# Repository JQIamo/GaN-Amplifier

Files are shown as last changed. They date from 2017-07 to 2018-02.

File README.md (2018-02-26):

# GaN-Amplifier
High-power, wideband RF amplifier designed by D. Barker and A. Restelli.
This design is released under the CERN Open Hardware License v1.2.

Primary documentation for the GaN amplifier can be found in the [Wiki](https://github.com/JQIamo/aom-driver/wiki/AOM-Driver-Wiki) for the [GaN-Amp-Compatible](https://github.com/JQIamo/aom-driver/tree/GaN-Amp-Compatible) branch of the AOM driver.

The eagle files in this repository will be much easier to use with [eagle-config](https://github.com/JQIamo/eagle-config) installed and configured.

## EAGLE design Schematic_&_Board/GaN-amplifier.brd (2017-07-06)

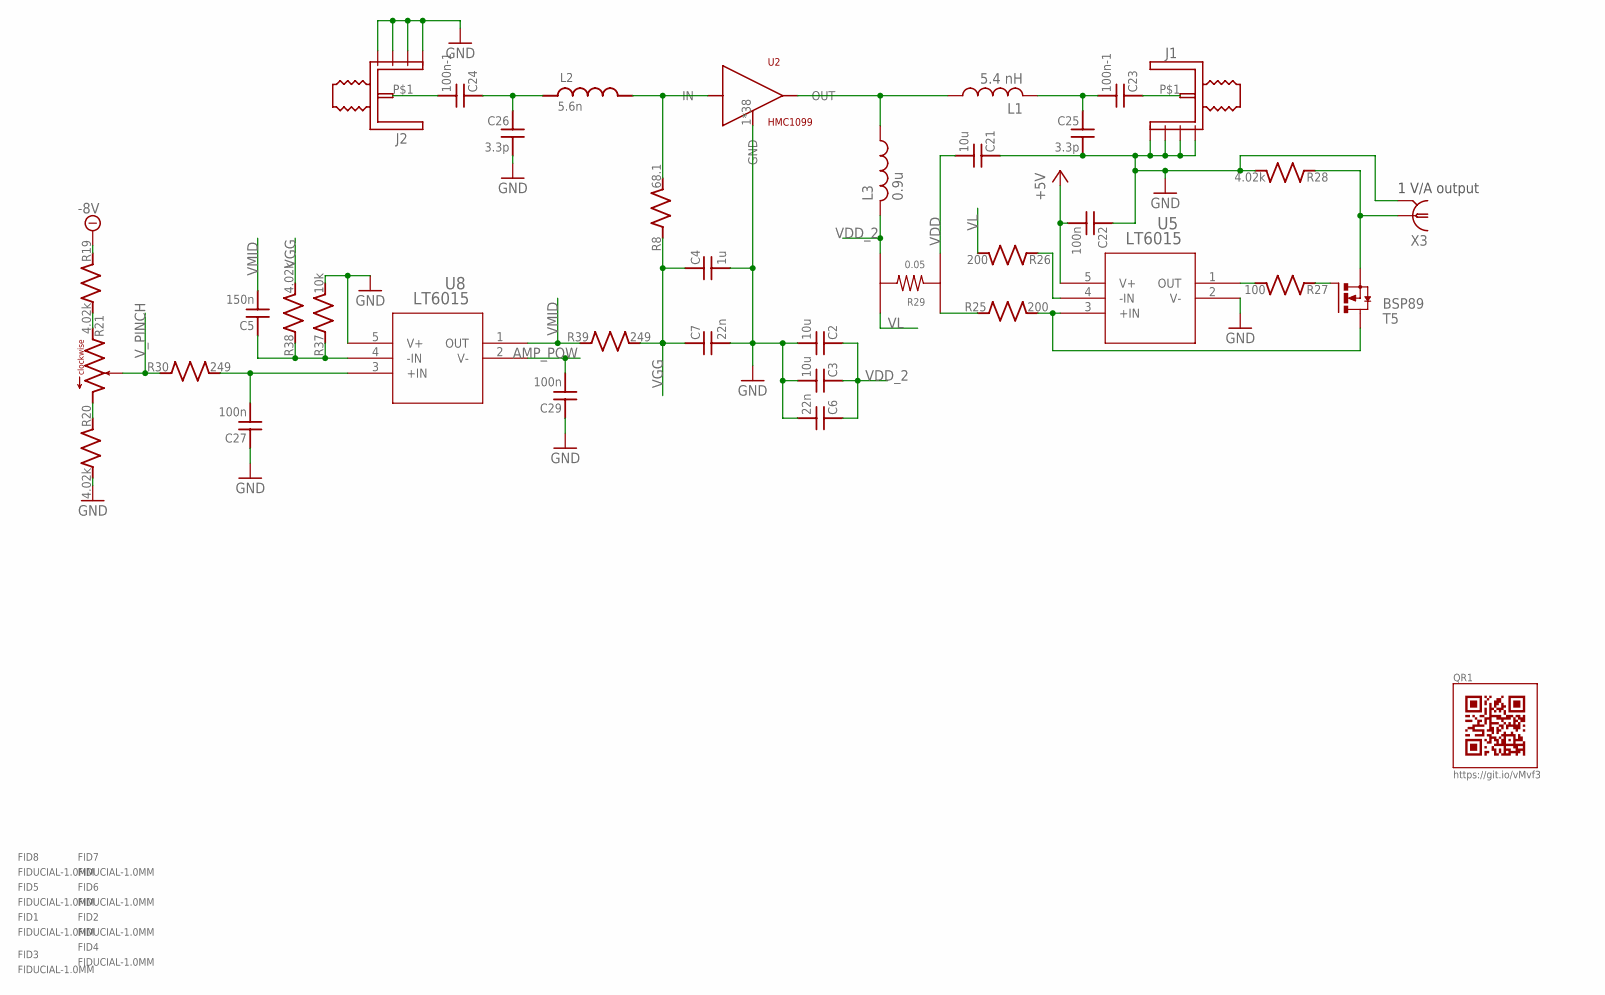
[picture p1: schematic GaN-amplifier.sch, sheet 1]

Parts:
C2, C3, C21: 10u; C_MLCC_1210; PARTNO CL32B106KBJNNNE
C4: 1u; C_MLCC_0603; PARTNO CL10B105KA8NNNC
C5: 150n; C_MLCC_0603; PARTNO CL10B154KO8NNNC
C6, C7: 22n; C_MLCC_0603; PARTNO CL10B223KB8NNNC
C22, C27, C29: 100n; C_MLCC_0603; PARTNO CL10B104KB8SFNC
C23, C24: 100n-1; C_MLCC_0402; PARTNO 0402BB104KW500
C25, C26: 3.3p; C_MLCC_0603; PARTNO 600S3R3CT250XT
FID1, FID2, FID3, FID4, FID5, FID6, FID7, FID8: FIDUCIAL-1.0MM; FID_1.0MM
J1, J2: JOHNSON_SMA_EDGE_LAUNCH_142-0701-851; PARTNO 142-0701-851
L1: 5.4 nH; 0906; PARTNO 0906-5JLB
L2: 5.6n; R_0402; PARTNO 0402CS-5N6XJLU
L3: 0.9u; 1008; PARTNO 1008AF-901XKLC
QR1: QR-HTTPS://GIT.IO/VMVF3-LIGHT-SILK
R8: 68.1; R_0603; PARTNO ERJ-3EKF68R1V
R19, R20, R28, R38: 4.02k; R_0603; PARTNO TNPW06034K02BEEA
R21: R_TRIM; RJ24; PARTNO Y006910K0000J9L
R25, R26: 200; R_0603; PARTNO TNPW0603200RBEEA
R27: 100; R_0603; PARTNO ERJ-3EKF1000V
R29: 0.05; 1206_KELVIN; PARTNO LVK12R050DER
R30, R39: 249; R_0603; PARTNO TNPW0603249RBEEA
R37: 10k; R_0603; PARTNO TNPW060310K0BEEA
T5: BSP89; PG-SOT-223; PARTNO BSP89H6327XTSA1
U2: HMC1099; HCP-32-2; PARTNO HMC1099LP5DE
U5, U8: LT6015; TSOT-23_S5; PARTNO LT6015HS5#TRMPBF
X3: BNC-V; PARTNO 5227222-3

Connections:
+5V: C22.P$2 (2), U5.5 (V+); also elsewhere on the board
-8V: R19.P$1 (1); also elsewhere on the board
AMP_POW: C29.P$2 (2), U8.2 (V-); also elsewhere on the board
GND: C2.P$2 (2), C3.P$2 (2), C4.P$2 (2), C6.P$2 (2), C7.P$2 (2), C21.P$1 (1), C22.P$1 (1), C25.P$2 (2), C26.P$2 (2), C27.P$1 (1), C29.P$1 (1), J1.P$2 (GND1), J1.P$3 (GND), J1.P$4 (GND2), J1.P$5 (GND3), J2.P$2 (GND1), J2.P$3 (GND), J2.P$4 (GND2), J2.P$5 (GND3), R20.P$2 (2), R28.P$2 (2), R37.P$2 (2), U2.1 (GND), U2.2 (GND), U2.3 (GND), U2.6 (GND), U2.7 (GND), U2.8 (GND), U2.9 (GND), U2.10 (GND), U2.11 (GND), U2.12 (GND), U2.13 (GND), U2.14 (GND), U2.15 (GND), U2.16 (GND), U2.17 (GND), U2.18 (GND), U2.19 (GND), U2.22 (GND), U2.23 (GND), U2.24 (GND), U2.25 (GND), U2.26 (GND), U2.27 (GND), U2.28 (GND), U2.29 (GND), U2.30 (GND), U2.31 (GND), U2.32 (GND), U2.33 (GND), U2.34 (GND), U2.35 (GND), U2.36 (GND), U2.37 (GND), U2.38 (GND), U2.39 (GND), U2.40 (GND), U2.41 (GND), U2.42 (GND), U5.2 (V-), U8.5 (V+), X3.2; also elsewhere on the board
unnamed: R19.P$2 (2), R21.1
unnamed: R20.P$1 (1), R21.3
unnamed: R25.P$2 (2), T5.2 (D), T5.4 (D), U5.3 (+IN)
unnamed: R27.P$2 (2), U5.1 (OUT)
unnamed: R27.P$1 (1), T5.1 (G)
unnamed: R25.P$1 (1), R29.P$1
unnamed: R28.P$1 (1), T5.3 (S), X3.1
unnamed: R26.P$1 (1), U5.4 (-IN)
unnamed: C23.P$1 (1), J1.P$1
unnamed: C24.P$2 (2), J2.P$1
unnamed: C5.P$1 (1), R37.P$1 (1), R38.P$1 (1), U8.4 (-IN)
unnamed: C23.P$2 (2), C25.P$1 (1), L1.P$2 (2)
unnamed: L1.P$1 (1), L3.P$1 (1), U2.20 (OUT), U2.21 (OUT)
unnamed: C24.P$1 (1), C26.P$1 (1), L2.P$1 (1)
unnamed: C27.P$2 (2), R30.P$2 (2), U8.3 (+IN)
VDD: C21.P$2 (2), R29.P$3; also elsewhere on the board
VDD_2: C2.P$1 (1), C3.P$1 (1), C6.P$1 (1), L3.P$2 (2), R29.P$4
VGG: C4.P$1 (1), C7.P$1 (1), R8.P$1 (1), R38.P$2 (2), R39.P$2 (2)
VL: R26.P$2 (2), R29.P$2
VMID: C5.P$2 (2), R39.P$1 (1), U8.1 (OUT)
V_GATE: L2.P$2 (2), R8.P$2 (2), U2.4 (IN), U2.5 (IN)
V_PINCH: R21.2, R30.P$1 (1); also elsewhere on the board

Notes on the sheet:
1 V/A output

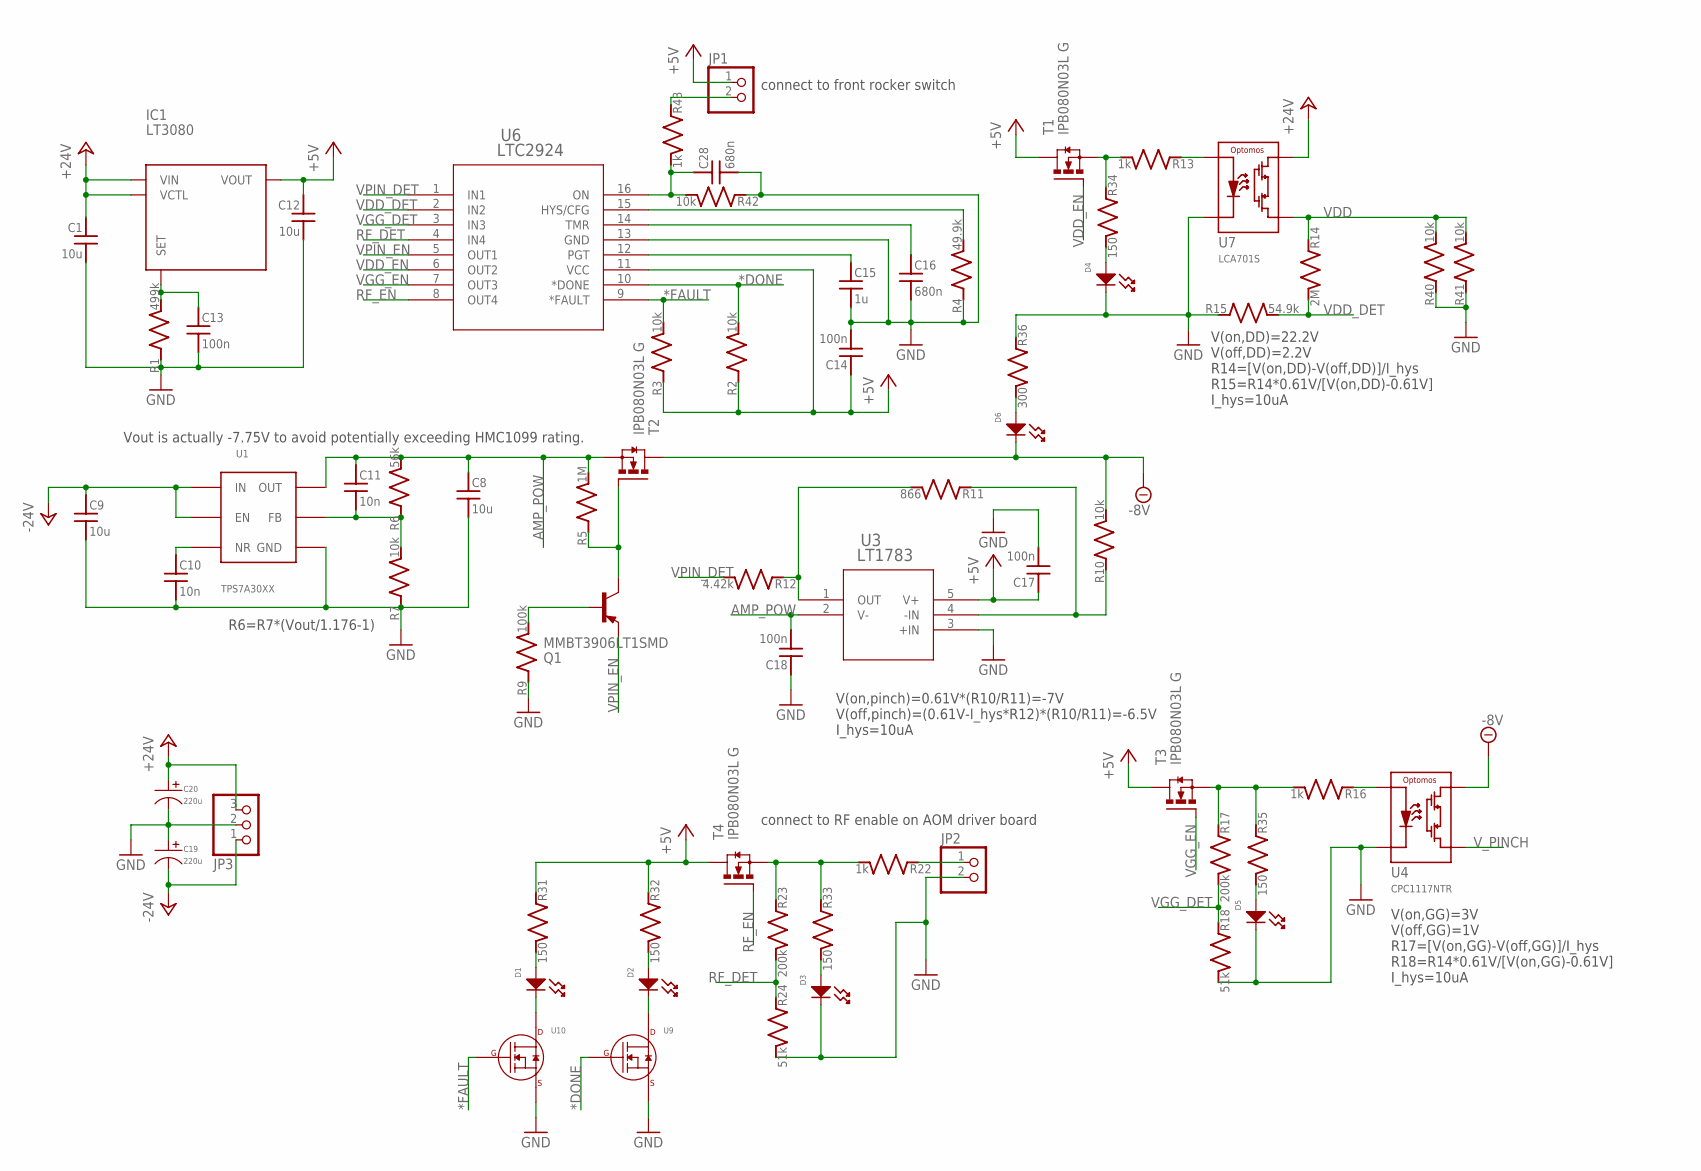
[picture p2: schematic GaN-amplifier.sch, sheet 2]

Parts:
C1, C8, C9, C12: 10u; C_MLCC_1210; PARTNO CL32B106KBJNNNE
C10, C11: 10n; C_MLCC_0402; PARTNO CL05B103KB5NNNC
C13, C14, C17, C18: 100n; C_MLCC_0603; PARTNO CL10B104KB8SFNC
C15: 1u; C_MLCC_0603; PARTNO CL10B105KA8NNNC
C16, C28: 680n; C_MLCC_0603; PARTNO CL10B684KO8NFNC
C19, C20: 220u; CP10MM; PARTNO MF-CAP-10MM-220uF
D1, D3, D4, D5, D6: LED_SINGLE-0603-GREEN; LED0603
D2: LED_SINGLE-0603-RED; LED0603
IC1: LT3080; TO263-5; PARTNO LT3080EQ#PBF
JP1, JP2: PINHD-1X2; 1X02; PARTNO 640456-2
JP3: PINHD-1X3; 1X03; PARTNO 640456-3
Q1: MMBT3906LT1SMD; SOT23-BEC; PARTNO MF-DSC-SOT233-MMBT3906
R1: 499k; R_0603; PARTNO ERJ-3EKF4993V
R2, R3, R10, R40, R41, R42: 10k; R_0603; PARTNO ERJ-3EKF1002V
R4: 49.9k; R_0603; PARTNO ERJ-3EKF4992V
R5: 1M; R_0603; PARTNO ERJ-3EKF1004V
R6: 56k; R_0402; PARTNO ERJ-2RKF5602X
R7: 10k; R_0402; PARTNO ERJ-2RKF1002X
R9: 100k; R_0603; PARTNO ERJ-3EKF1003V
R11: 866; R_0603; PARTNO ERJ-3EKF8660V
R12: 4.42k; R_0603; PARTNO ERJ-3EKF4421V
R13, R16, R22, R43: 1k; R_0603; PARTNO ERJ-3EKF1001V
R14: 2M; R_0603; PARTNO ERJ-3EKF2004V
R15: 54.9k; R_0603; PARTNO ERJ-3EKF5492V
R17, R23: 200k; R_0603; PARTNO ERJ-3EKF2003V
R18, R24: 51k; R_0603; PARTNO ERJ-3EKF5102V
R31, R32, R33, R34, R35: 150; R_0603; PARTNO ERJ-3EKF1500V
R36: 300; R_0603; PARTNO ERJ-PA3F3000V
T1, T2, T3, T4: IPB080N03L G; D2PACK; PARTNO IPB080N03L G
U1: TPS7A30XX; DGN; PARTNO TPS7A3001DGNR
U3: LT1783; TSOT-23_S5; PARTNO LT1783HS5#TRMPBF
U4: CPC1117NTR; 4-LEAD_SOP; PARTNO CPC1117NTR
U6: LTC2924; SSOP-16_GN; PARTNO LTC2924IGN#PBF
U7: LCA701S; 6-LEAD_SMT; PARTNO LCA701S
U9, U10: N-CHANNEL_FET_BSS138_SOT-23-3; SOT-23-3

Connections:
*DONE: R2.P$2 (2), U6.10 (*DONE), U9.P$1 (GATE)
*FAULT: R3.P$2 (2), U6.9 (*FAULT), U10.P$1 (GATE)
+5V: C12.P$1 (1), C14.P$1 (1), C17.P$1 (1), IC1.3 (VOUT), IC1.6 (VOUT), JP1.1, R2.P$1 (1), R3.P$1 (1), R31.P$1 (1), R32.P$1 (1), T1.2 (D), T3.2 (D), T4.2 (D), U3.5 (V+), U6.11 (VCC); also elsewhere on the board
+24V: C1.P$1 (1), C20.P$1, IC1.4 (VCTL), IC1.5 (VIN), JP3.3, U7.6 (L+)
-8V: D6.CATHODE, R10.P$2 (2), T2.2 (D), U4.P$4 (L+); also elsewhere on the board
-24V: C9.P$1 (1), C19.P$2, JP3.1, U1.EN, U1.IN
AMP_POW: C8.P$1 (1), C11.P$1 (1), C18.P$2 (2), R5.P$2 (2), R6.P$2 (2), T2.3 (S), U1.OUT, U3.2 (V-); also elsewhere on the board
GND: C1.P$2 (2), C8.P$2 (2), C9.P$2 (2), C10.P$2 (2), C12.P$2 (2), C13.P$2 (2), C14.P$2 (2), C15.P$2 (2), C16.P$2 (2), C17.P$2 (2), C18.P$1 (1), C19.P$1, C20.P$2, C28.P$2 (2), D3.CATHODE, D4.CATHODE, D5.CATHODE, JP2.2, JP3.2, R1.P$1 (1), R4.P$1 (1), R7.P$1 (1), R9.P$1 (1), R15.P$1 (1), R18.P$2 (2), R24.P$2 (2), R36.P$1 (1), R40.P$1 (1), R41.P$1 (1), R42.P$1 (1), U1.GND, U1.GND1 (GND), U3.3 (+IN), U4.P$2 (C-), U6.13 (GND), U7.2 (C-), U9.P$2 (SOURCE), U10.P$2 (SOURCE); also elsewhere on the board
unnamed: C13.P$1 (1), IC1.2 (SET), R1.P$2 (2)
unnamed: D1.CATHODE, U10.P$3 (DRAIN)
unnamed: D2.CATHODE, U9.P$3 (DRAIN)
unnamed: JP1.2, R43.P$1 (1)
unnamed: C16.P$1 (1), U6.14 (TMR)
unnamed: R4.P$2 (2), U6.15 (HYS/CFG)
unnamed: C15.P$1 (1), U6.12 (PGT)
unnamed: R11.P$2 (2), R12.P$1 (1), U3.1 (OUT)
unnamed: Q1.C, R5.P$1 (1), T2.1 (G)
unnamed: Q1.B, R9.P$2 (2)
unnamed: R13.P$2 (2), R34.P$1 (1), T1.3 (S)
unnamed: R10.P$1 (1), R11.P$1 (1), U3.4 (-IN)
unnamed: R13.P$1 (1), U7.1 (C+)
unnamed: R16.P$2 (2), R17.P$1 (1), R35.P$1 (1), T3.3 (S)
unnamed: C11.P$2 (2), R6.P$1 (1), R7.P$2 (2), U1.FB
unnamed: R16.P$1 (1), U4.P$1 (C+)
unnamed: C10.P$1 (1), U1.NR/SS (NR)
unnamed: D1.ANODE, R31.P$2 (2)
unnamed: R22.P$2 (2), R23.P$1 (1), R33.P$1 (1), T4.3 (S)
unnamed: JP2.1, R22.P$1 (1)
unnamed: D2.ANODE, R32.P$2 (2)
unnamed: D4.ANODE, R34.P$2 (2)
unnamed: D3.ANODE, R33.P$2 (2)
unnamed: D5.ANODE, R35.P$2 (2)
unnamed: D6.ANODE, R36.P$2 (2)
unnamed: C28.P$1 (1), R42.P$2 (2), R43.P$2 (2), U6.16 (ON)
RF_DET: R23.P$2 (2), R24.P$1 (1), U6.4 (IN4)
RF_EN: T4.1 (G), U6.8 (OUT4)
VDD: R14.P$1 (1), R40.P$2 (2), R41.P$2 (2), U7.4 (L-); also elsewhere on the board
VDD_DET: R14.P$2 (2), R15.P$2 (2), U6.2 (IN2)
VDD_EN: T1.1 (G), U6.6 (OUT2)
VGG_DET: R17.P$2 (2), R18.P$1 (1), U6.3 (IN3)
VGG_EN: T3.1 (G), U6.7 (OUT3)
VPIN_DET: R12.P$2 (2), U6.1 (IN1)
VPIN_EN: Q1.E, U6.5 (OUT1)
V_PINCH: U4.P$3 (L-); also elsewhere on the board

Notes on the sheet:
Vout is actually -7.75V to avoid potentially exceeding HMC1099 rating.
R6=R7*(Vout/1.176-1)
connect to front rocker switch
V(on,pinch)=0.61V*(R10/R11)=-7V V(off,pinch)=(0.61V-I_hys*R12)*(R10/R11)=-6.5V I_hys=10uA
V(on,DD)=22.2V V(off,DD)=2.2V R14=[V(on,DD)-V(off,DD)]/I_hys R15=R14*0.61V/[V(on,DD)-0.61V] I_hys=10uA
V(on,GG)=3V V(off,GG)=1V R17=[V(on,GG)-V(off,GG)]/I_hys R18=R14*0.61V/[V(on,GG)-0.61V] I_hys=10uA
connect to RF enable on AOM driver board

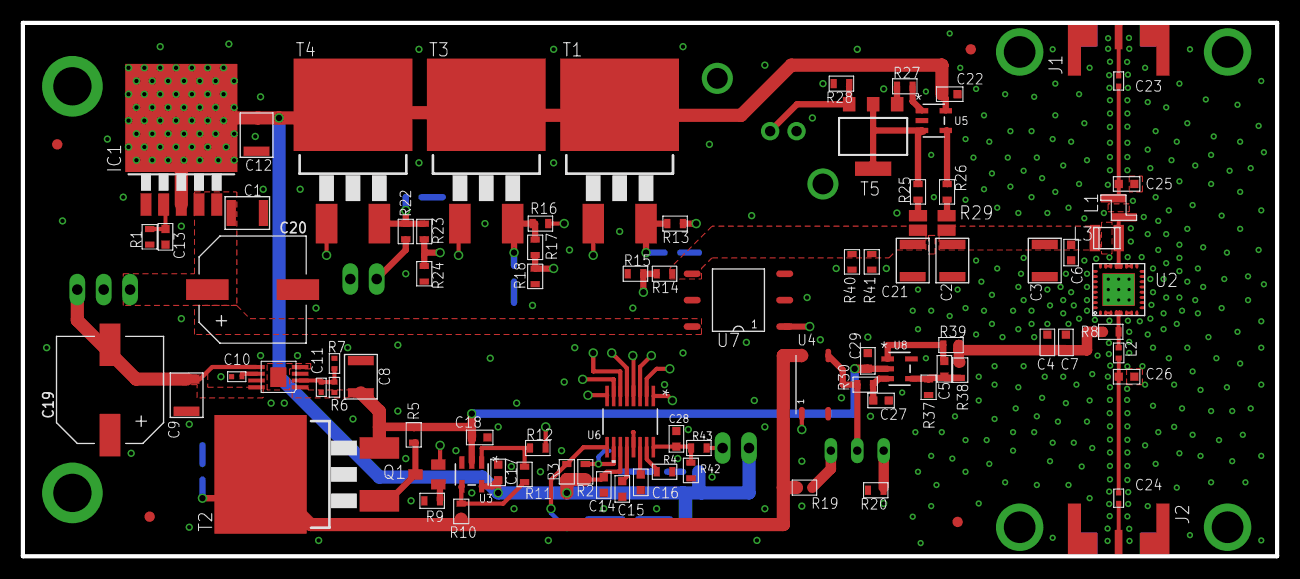
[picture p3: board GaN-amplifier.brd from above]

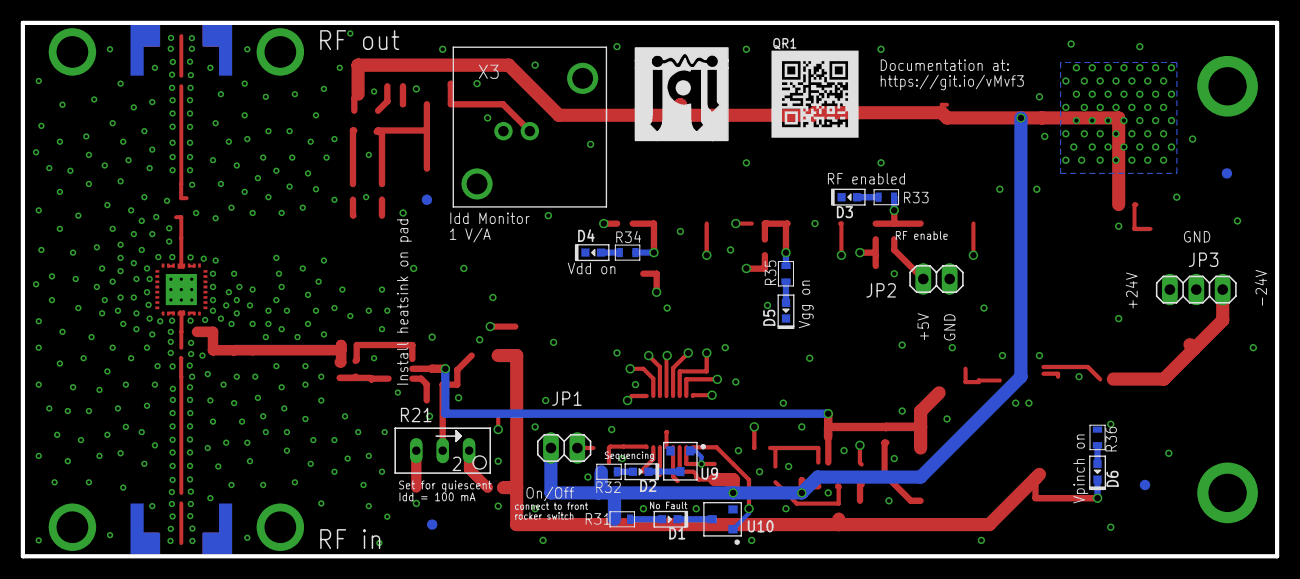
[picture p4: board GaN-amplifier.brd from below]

Board: 4 copper layers, 120.7 x 51.3 mm, 114 parts (25 on the bottom side), 64 nets.

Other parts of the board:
U$2: JQI_LOGO_NEGATIVE-SILKSCREEN

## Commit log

2016-11-29 Initial Push
    Started circuit design for the GaN amplifier.
    DSB
    [GaN-amplifier.brd, GaN-amplifier.sch]
2016-11-30 Mostly designed power sequencing
    This will all almost certainly be trashed, but it's a start.
    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
    [GaN-amplifier.brd, GaN-amplifier.sch]
2016-12-02 Change power sequencing
    Switched to using LTC2924 for power sequencing.
    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
    [GaN-amplifier.brd, GaN-amplifier.sch]
2016-12-05 Halfway done with power sequencing
    The gate voltage supply and bias supply sequencing should be good to
    go. Still need to set up the gate voltage and RF power lockout.
    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
    [GaN-amplifier.brd, GaN-amplifier.sch]
2016-12-05 Quick Sync to talk sequencing with AR
    A few more updates to discuss.
    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
    [GaN-amplifier.brd, GaN-amplifier.sch]
2016-12-07 Starting Vgg Control
    Started setting up the power sequencing and setpoint control for the
    amplifier gate voltage.
    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
    [GaN-amplifier.brd, GaN-amplifier.sch]
2016-12-08 Finished Power Sequencing
    Completed the power sequencing section. Starting on the RF amp section.
    Need to track down the correct inductors.
    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
    [GaN-amplifier.brd, GaN-amplifier.sch]
2016-12-09 Mostly done with schematic
    Just need to find that damn bias-t inductor.
    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
    [GaN-amplifier.brd, GaN-amplifier.sch]
2016-12-12 Finished Schematic
    Found a bias inductor, so the schematic is finished. I'll want to get
    the board layed out this week so that a test piece can be ordered before
    Xmas.
    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
    [GaN-amplifier.brd, GaN-amplifier.sch]
2016-12-12 Started board layout
    Moved all the components so they fit in the allowed area. Need to
    detangle air wires next.
    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
    [GaN-amplifier.brd]
2016-12-14 Parts positioned
    I've positioned the components. Now routing needs to happen.
    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
    [GaN-amplifier.brd, GaN-amplifier.sch]
2016-12-15 Few adjustments
    Rearranged the board to be a bit more compact.
    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
    [GaN-amplifier.brd]
2016-12-16 Power Sequencing Layed Out
    I've finished routing the power sequencing part of the PCB. Need to copy
    positions of RF components from eval board gerber and design 50 Ohm
    striplines.
    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
    [GaN-amplifier.brd, GaN-amplifier.sch]
2016-12-19 Add VGG Buffer
    Added buffer for the GaN amp gate voltage. Also made progress on RF
    layout.
    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
    [GaN-amplifier.brd, GaN-amplifier.sch]
2016-12-20 Routed Buffer
    I’ve routed the gate bias buffer part of the circuit. The only thing
    that’s left is routing the RF traces.
    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
    [GaN-amplifier.brd, GaN-amplifier.sch]
2016-12-20 Finished Layout, Starting BOM
    I've finished the layout up to getting final RF trace widths set (per
    manufacturer specs) and started compiling a BOM.
    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
    [GaN-amplifier.brd, GaN-amplifier.sch]
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2016-12-21 Finalizing Design
    I've almost finalized the design. Just need to order the HMC1099 and
    ensure that Macrofab can do the job properly.
    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
    [GaN-amplifier.brd, GaN-amplifier.sch]
2016-12-22 Updated BOM and Mirrored Parts
    Changed BOM for better compatibility with MacroFab. Changed the
    through-hole components to populate on the bottom of the board.
    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
    [GaN-amplifier.brd, GaN-amplifier.sch]
2016-12-22 Added Error Monitor LEDs
    Added a couple LEDs to indicate the status of the power sequencer.
    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
    [GaN-amplifier.brd, GaN-amplifier.sch]
2016-12-23 QR and more LEDs
    I added a few more indicator LEDs and a QR code that points to the
    repository.
    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
    [GaN-amplifier.brd, GaN-amplifier.sch]
2017-01-03 Prepared to order
    Made a few adjustments based on Alessandro's suggestions. Ready to order
    once consigned parts arrive.
    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
    [GaN-amplifier.brd, GaN-amplifier.sch]
2017-01-11 Fixes per Alessandro
    Added LP-filter for gate voltage and GND plane cutouts to improve RF
    performance. Also switched a few components for equivalent parts to
    reduce cost.
    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
    [GaN-amplifier.GBL, GaN-amplifier.GBO, GaN-amplifier.GBP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]
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2017-01-11 Separate RF and Sequencing
    I've moved the RF and power sequencing portions of the circuit diagram
    to separate sheets for readability.
    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
    [GaN-amplifier.brd, GaN-amplifier.sch]
2017-01-12 Moved few vias nearer to the RF microstrip
    Please check that the LTC1152 is not modulating the amplitude of the RF
    carrier at 4 MHz introducing sidebands.
    [GaN-amplifier.brd]
2017-01-12 New Vgg Buffer
    Changed out the Vgg buffer IC to reduce noise.
    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
    [GaN-amplifier.brd, GaN-amplifier.sch]
2017-03-04 Fixed U4 package
    Updated board layout with correct optomos package.
    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
    [GaN-amplifier.brd, GaN-amplifier.sch]
2017-03-13 Updates per test board
    Adding pulldown on Vdd and On/Off to prevent errors during power
    sequencing. Also increasing capacitance of AC coupling capacitors for
    better low frequency performance. A couple cosmetic changes to make
    component labels visible.
    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
    [GaN-amplifier.brd, GaN-amplifier.sch]
2017-04-20 More test board updates
    Adjusted fiducial position per Zach's advice and added switch debouncing
    components.
    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
    [GaN-amplifier.brd, GaN-amplifier.sch]
2017-05-09 Changed coupling caps
    I changed the RF coupling capacitors to a lower ESR component. We should
    consider an ultra-broadband cap also, but the expense seems excessive.
    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
    [GaN-amplifier.brd, GaN-amplifier.sch]
2017-05-17 Enlarging heatsink pad
    Enlarging the pad for the backside heatsink and adding vias for better
    power dissipation.
    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
    [GaN-amplifier.brd, GaN-amplifier.sch]
2017-05-19 Updated BOM and hole positions
    I've changed a couple parts in the BOM and adjusted the position of
    mounting holes to accomodate the new heatsink.
    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
    [GaN-amplifier.brd, GaN-amplifier.sch]
2017-06-01 Cosmetic Changes
    Adjusted position of RF in/out labels for visibility with larger
    heatsink.
    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
    [GaN-amplifier.brd]
2017-06-14 Adjusted hole sizes
    Changed the mounting hole sizes to increase flexibility.
    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
    [GaN-amplifier.brd]
2017-07-06 Better Thermal Management
    Added Vias for better heat dissipation from voltage regulators.
    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
    [GaN-amplifier.brd, GaN-amplifier.sch]

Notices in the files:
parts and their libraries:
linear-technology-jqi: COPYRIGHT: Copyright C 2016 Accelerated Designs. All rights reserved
